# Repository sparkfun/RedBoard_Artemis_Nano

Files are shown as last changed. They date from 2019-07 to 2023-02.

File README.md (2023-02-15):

SparkFun RedBoard Artemis Nano
============================

SparkFun RedBoard Artemis Nano

[*SparkFun RedBoard Artemis Nano (DEV-15443)*](https://www.sparkfun.com/products/15443)

We like to joke the Artemis Nano is a party on the front and business on the back. And that's by design! All the important LEDs, connectors, labels, and buttons are presented on the front for the best user experience with all the supporting circuitry on the rear of the board. The RedBoard Artemis Nano is a minimal but extremely handy implementation of the Artemis module. A light weight, 0.8mm thick PCB, with on board lipo-battery charging and a Qwiic connector, this board is easy to implement into very small projects. A dual row of ground connections make it easy to add lots of buttons, LEDs, and anything that requires its own GND connection. At the same time, the board is breadboard compatible! 

A modern USB-C connector makes programming easy. The Nano is fully compatible with the SparkFun's Arduino core and can be programmed easily under the Arduino IDE. We've also exposed the JTAG connector for more advanced users who prefer to use the power and speed of professional tools. If you're looking for a simple, cost-effective board to replace your aging Arduino Uno or Arduino Nano, look no further. We've even added a digital MEMS microphone for folks wanting to experiment with always-on voice commands with TensorFlow and machine learning.
 
With 1M flash and 384k RAM you'll have plenty of room for your sketches. The Artemis module runs at 48MHz with a 96MHz turbo mode available and with Bluetooth to boot!

The SparkFun Artemis Nano is an incredibly flexible device for a small footprint but if you're looking for all the bells and whistles, be sure to checkout our RedBoard and ATP footprints for even more I/O and capabilities.

Repository Contents
-------------------
* **/Hardware** - Eagle design files (.brd, .sch)

Documentation
-------------------
* **[Hookup Guide for the RedBoard Artemis Nano](https://learn.sparkfun.com/tutorials/hookup-guide-for-the-sparkfun-redboard-artemis-nano)**
* **[Fritzing Part](https://github.com/sparkfun/Fritzing_Parts/blob/main/products/15443_sfe_redboard_artemis_nano.fzpz)** - Fritzing diagrams for SparkFun products.
* **[Artemis Development with Arduino](https://learn.sparkfun.com/tutorials/artemis-development-with-arduino)**
* **[Ambiq Apollo3 SDK SetUp](https://learn.sparkfun.com/tutorials/using-sparkfun-edge-board-with-ambiq-apollo3-sdk)**
* **[Designing with the SparkFun Artemis](https://learn.sparkfun.com/tutorials/designing-with-the-sparkfun-artemis)**
* **[CH340E USB to serial IC Drivers](https://www.sparkfun.com/ch340)**

License Information
-------------------

This product is _**open source**_! 

Please review the LICENSE.md file for license information. 

If you have any questions or concerns on licensing, please contact techsupport@sparkfun.com.

Please use, reuse, and modify these files as you see fit. Please maintain attribution to SparkFun Electronics and release any derivative under the same license.

Distributed as-is; no warranty is given.

- Your friends at SparkFun.

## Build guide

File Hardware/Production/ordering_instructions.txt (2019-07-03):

panel size, 213x97mm
PCB thickness, 0.8mm
number of layers, 4
soldermask color, Red
silkscreen color, White
oz copper, 1oz
finish, HASL lead free
stencils, top+bottom
pcs per panel, 16
min trace width, 0.152400mm / 0.006000in
min drill size, 0.304800mm / 0.012000in
filename to layer stackup 1/2/3/4: GTL, GL2, GL3, GBL

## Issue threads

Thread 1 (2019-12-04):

Expose ITM/SWO pin on SWD/JTAG Connector

oclyke, 2019-12-04:
Will you consider adding a free ITM/SWO pin to the SWD/JTAG connector as is demonstrated on the [Edge](https://cdn.sparkfun.com/assets/2/b/7/4/d/SparkFun_Edge_Schematic.pdf) board? This affords users a different ('pro') way to do debug printing and possibly frees up a UART for another purpose. Inspired by https://github.com/sparkfun/SparkFun_Apollo3_AmbiqSuite_BSPs/issues/19

oclyke, 2019-12-13:
OOPS. I totally overlooked the SWO pin here and made all this fuss over nothing. Sorry!

Closed 2019-12-13.

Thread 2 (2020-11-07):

Which USB C Connector is used ?

Thore-Krug, 2020-11-07:
I wanted to know which USB C Connector was used on the Board and opened the Design Files but there is no info on the Specific USB Connector used.   I also noted that the libary used for the connector was not included in the Design Files.

Signed off by: Thore Krug opensource[at]thorekrug.de

nseidle, 2020-11-09:
[This one](https://www.sparkfun.com/products/15111) from BSC.

Thore-Krug, 2020-11-09:
Thank you

Closed 2020-11-09.

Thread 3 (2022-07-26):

Hardware Feature request/suggestions

edringel, 2022-07-26:
Forgive me if I've done this incorrectly, but here goes--
I'd like to suggest an Artemis based board designed to maximize low power features. I'm using the Artemis Nano in a remote sensor that is turned on and off by a low power timer. Once I am done with development, I will be cutting traces, and removing SMD resistors and LEDs to minimize current draw. I think one of the draws of the Artemis is its super low power potential, and a board designed to maximize that facet of use might rouse some interest. The design changes are simple (I think) and would be great for a project sitting off in the woods running on battery for months at a time--

Rather than a design paradigm assuming that the device is mostly on and occasionally needs to be turned off, consider a design that assumes that the device is mostly off and is turned on periodically to do something and then gets turned off. Would pair nicely with Adafruit TPL5111 (NOT the TPL5110, which is slightly different.) Or you guys could cobble together your own ;)
1) Do not use a pullup resistor for the regulator's enable pin. Every time the enable pin is brought low by tying it to ground, there is current through the 10K resistor which over time adds up. Use either a high resistance pulldown resistor or leave it to the user.
2) All LEDs have a trace that can be cut so that they no longer are active. Once design work is done, cutting the traces would reduce current by milliamps.
3) No microphone.
4) Hobbyist level library to shut off unneeded peripherals. Something nice and Arduino IDE friendly
Thanks for considering this.
Ed

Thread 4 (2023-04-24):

Using with a LiPo cell + solar panel

jerabaul29, 2023-04-24:
Is it enough to simply:

- connect a LiPo cell on the battery connector,
- connect a 6V solar panel between the Vin and GND

to use the RedBoard Nano with LiPo + Solar panel? If so, maybe having a dedicated section / explanation in addition to what is already present in the product page would be good, just to discuss this combination; if I did not miss anything, there is no detailed documentation on this available yet :) . If not, any other way to get a combination RedBoard Artemis Nano + LiPo + solar panel working with as little work as possible? :)

(what we were discussing about @gauteh :) ).

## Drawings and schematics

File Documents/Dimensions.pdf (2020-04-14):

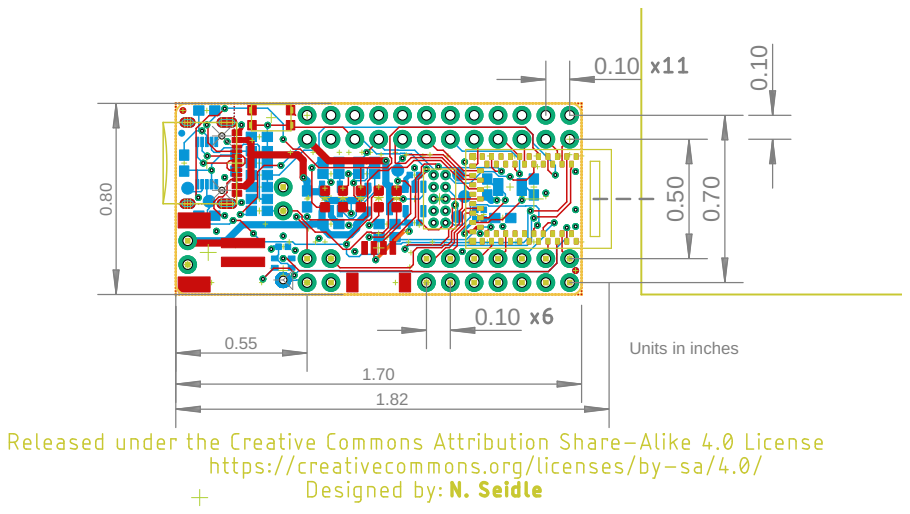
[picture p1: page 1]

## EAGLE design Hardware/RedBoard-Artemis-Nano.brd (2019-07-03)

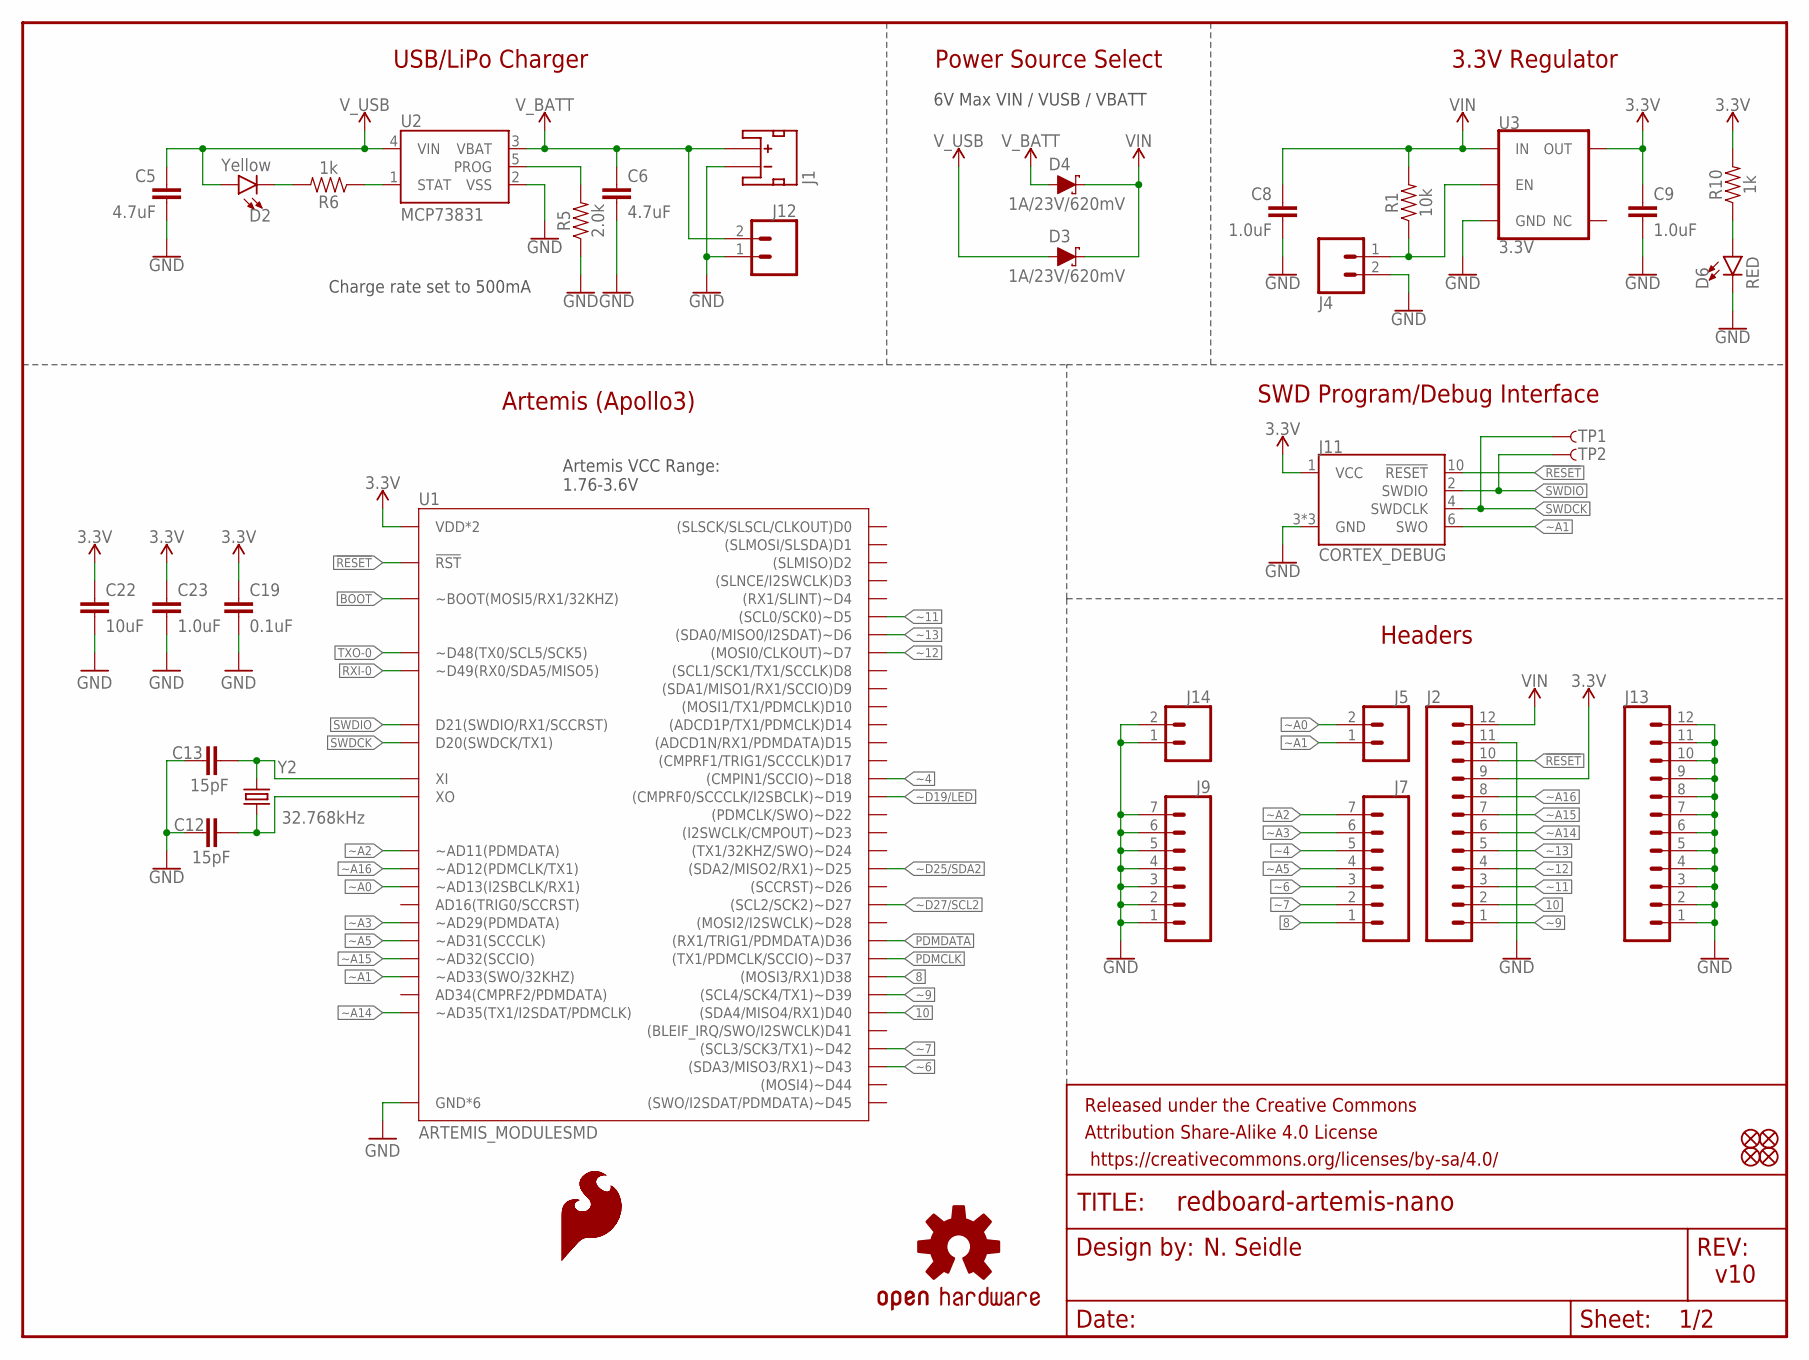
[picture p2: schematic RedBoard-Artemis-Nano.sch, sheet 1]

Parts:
C5, C6: 4.7uF; 0603
C8, C9, C23: 1.0uF; 0402-TIGHT
C12, C13: 15pF; 0603
C19: 0.1uF; 0402-TIGHT
C22: 10uF; 0603
D2: Yellow; LED-0603
D3, D4: 1A/23V/620mV; SOD-323
D6: RED; LED-0603
FD1, FD2, FD3, FD4: FIDUCIALUFIDUCIAL; FIDUCIAL-MICRO
FRAME1: FRAME-LETTER; CREATIVE_COMMONS
J1: JST_2MM_MALE; JST-2-SMD
J2, J13: CONN_12NO_SILK; 1X12_NO_SILK
J4, J5, J12, J14: CONN_021X02_NO_SILK; 1X02_NO_SILK
J7, J9: CONN_07NO_SILK; 1X07_NO_SILK
J11: CORTEX_DEBUG; 2X5-PTH-1.27MM-NO_SILK
LOGO1, LOGO4: SFE_LOGO_FLAME.1_INCH; SFE_LOGO_FLAME_.1
LOGO2: OSHW-LOGONO_SILK; DUMMY
R1: 10k; 0603
R5: 2.0k; 0603
R6, R10: 1k; 0603
TP1, TP2: TEST-POINT3X5; PAD.03X.05
U1: ARTEMIS_MODULESMD; ARTEMIS_FP
U2: MCP73831; SOT23-5
U3: 3.3V; SOT23-5
Y2: 32.768kHz; CRYSTAL-SMD-3.2X1.5MM

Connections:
3.3V: C9.1, C19.2, C22.1, C23.1, J2.9, J11.1 (VCC), R10.2, U1.VDD@36 (VDD*2), U1.VDD@37 (VDD*2), U3.5 (OUT); also elsewhere on the board
8: J7.1, U1.D38 ((MOSI3/RX1)D38)
10: J2.2, U1.D40 ((SDA4/MISO4/RX1)D40)
!RESET: J2.10, J11.10 (!RESET), U1.~RST (!RST); also elsewhere on the board
BOOT: U1.BOOT (~BOOT(MOSI5/RX1/32KHZ)); also elsewhere on the board
GND: C5.2, C6.2, C8.2, C9.2, C12.1, C13.1, C19.1, C22.2, C23.2, D6.C, J1.1 (-), J2.11, J4.2, J9.1, J9.2, J9.3, J9.4, J9.5, J9.6, J9.7, J11.3 (GND), J11.5 (GND), J11.9 (GND), J12.1, J13.1, J13.2, J13.3, J13.4, J13.5, J13.6, J13.7, J13.8, J13.9, J13.10, J13.11, J13.12, J14.1, J14.2, R5.1, U1.GND@1 (GND*6), U1.GND@22 (GND*6), U1.GND@38 (GND*6), U1.GND@39 (GND*6), U1.GND@47 (GND*6), U1.GND@59 (GND*6), U2.2 (VSS), U3.2 (GND); also elsewhere on the board
unnamed: R5.2, U2.5 (PROG)
unnamed: C12.2, U1.XO, Y2.P$2 (2)
unnamed: D2.C, R6.2
unnamed: R6.1, U2.1 (STAT)
unnamed: C13.2, U1.XI, Y2.P$1 (1)
unnamed: D6.A, R10.1
PDMCLK: U1.~D37 ((TX1/PDMCLK/SCCIO)~D37); also elsewhere on the board
PDMDATA: U1.D36 ((RX1/TRIG1/PDMDATA)D36); also elsewhere on the board
RXI-0: U1.RXI-0 (~D49(RX0/SDA5/MISO5)); also elsewhere on the board
SWDCK: J11.4 (SWDCLK), TP1.P$1, U1.SWDCK (D20(SWDCK/TX1))
SWDIO: J11.2 (SWDIO), TP2.P$1, U1.SWDIO (D21(SWDIO/RX1/SCCRST))
TXO-0: U1.TXO-0 (~D48(TX0/SCL5/SCK5)); also elsewhere on the board
VIN: C8.1, D3.C, D4.C, J2.12, R1.2, U3.1 (IN)
VREG_EN: J4.1, R1.1, U3.3 (EN)
V_BATT: C6.1, D4.A, J1.2 (+), J12.2, U2.3 (VBAT)
V_USB: C5.1, D2.A, D3.A, U2.4 (VIN); also elsewhere on the board
~4: J7.5, U1.~D18 ((CMPIN1/SCCIO)~D18)
~6: J7.3, U1.~D43 ((SDA3/MISO3/RX1)~D43)
~7: J7.2, U1.~D42 ((SCL3/SCK3/TX1)~D42)
~9: J2.1, U1.~D39 ((SCL4/SCK4/TX1)~D39)
~11: J2.3, U1.~D5 ((SCL0/SCK0)~D5)
~12: J2.4, U1.D7 ((MOSI0/CLKOUT)~D7)
~13: J2.5, U1.~D6 ((SDA0/MISO0/I2SDAT)~D6)
~A0: J5.2, U1.~AD13 (~AD13(I2SBCLK/RX1))
~A1: J5.1, J11.6 (SWO), U1.~AD33/SWO (~AD33(SWO/32KHZ))
~A2: J7.7, U1.~AD11 (~AD11(PDMDATA))
~A3: J7.6, U1.~AD29 (~AD29(PDMDATA))
~A5: J7.4, U1.~AD31 (~AD31(SCCCLK))
~A14: J2.6, U1.~AD35 (~AD35(TX1/I2SDAT/PDMCLK))
~A15: J2.7, U1.~AD32 (~AD32(SCCIO))
~A16: J2.8, U1.~AD12 (~AD12(PDMCLK/TX1))
~D19/LED: U1.~D19 ((CMPRF0/SCCCLK/I2SBCLK)~D19); also elsewhere on the board
~D25/SDA2: U1.~D25 ((SDA2/MISO2/RX1)~D25); also elsewhere on the board
~D27/SCL2: U1.~D27 ((SCL2/SCK2)~D27); also elsewhere on the board

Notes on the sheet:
v10
N. Seidle
SWD Program/Debug Interface
Headers
Artemis (Apollo3)
USB/LiPo Charger
Power Source Select
3.3V Regulator
Artemis VCC Range: 1.76-3.6V
Charge rate set to 500mA
6V Max VIN / VUSB / VBATT

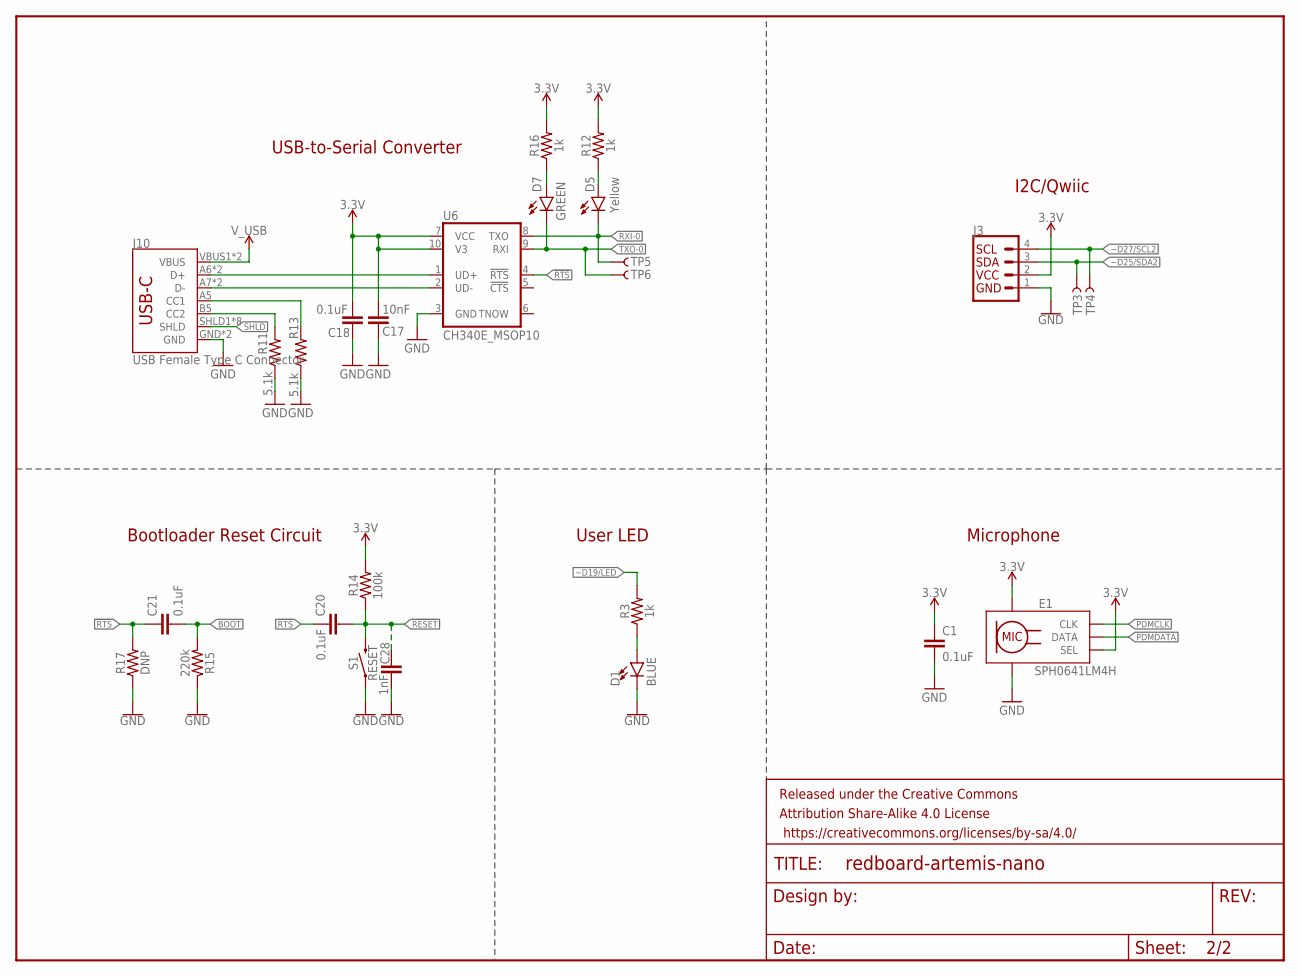
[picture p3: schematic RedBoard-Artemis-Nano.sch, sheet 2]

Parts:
C1: 0.1uF; 0402-TIGHT
C17: 10nF; 0603
C18, C20, C21: 0.1uF; 0603
C28: 1nF; 0603
D1: BLUE; LED-0603
D5: Yellow; LED-0603
D7: GREEN; LED-0603
E1: SPH0641LM4H; SPH0641LM4H-1_MICROPHONE
FRAME2: FRAME-LETTERNO_PACKAGE; DUMMY
J3: QWIIC_CONNECTORJS-1MM; JST04_1MM_RA
J10: USB Female Type C Connector; USB-C-16P-4LAYER-ISOLATED
R3, R12, R16: 1k; 0603
R11, R13: 5.1k; 0603
R14: 100k; 0603
R15: 220k; 0603
R17: DNP; 0603
S1: RESET; TACTILE_SWITCH_SMD_4.6X2.8MM
TP3, TP4, TP5, TP6: TEST-POINT3X5; PAD.03X.05
U6: CH340E_MSOP10; MSOP10

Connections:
3.3V: C1.1, C17.1, C18.1, E1.2 (SEL), E1.5 (VDD), J3.2, R12.2, R14.2, R16.2, U6.7 (VCC), U6.10 (V3); also elsewhere on the board
!RESET: C20.2, C28.1, R14.1, S1.3 (2), S1.4 (2); also elsewhere on the board
!RTS: C20.1, C21.1, R17.2, U6.4 (!RTS)
BOOT: C21.2, R15.2; also elsewhere on the board
CC1: J10.A5 (CC1), R13.2
CC2: J10.B5 (CC2), R11.2
D+1: J10.A6 (D+), J10.B6 (D+), U6.1 (UD+)
D-1: J10.A7 (D-), J10.B7 (D-), U6.2 (UD-)
GND: C1.2, C17.2, C18.2, C28.2, D1.C, E1.3 (GND), E1.6 (GND), E1.7 (GND), E1.8 (GND), J3.1, J10.GND, J10.GND2 (GND), R11.1, R13.1, R15.1, R17.1, S1.1, S1.2 (1), U6.3 (GND); also elsewhere on the board
unnamed: D7.A, R16.1
unnamed: D1.A, R3.1
unnamed: D5.A, R12.1
PDMCLK: E1.4 (CLK); also elsewhere on the board
PDMDATA: E1.1 (DATA); also elsewhere on the board
RXI-0: D5.C, TP5.P$1, U6.8 (TXO); also elsewhere on the board
SHLD: J10.SHLD1 (SHLD), J10.SHLD2 (SHLD), J10.SHLD3 (SHLD), J10.SHLD4 (SHLD), J10.SHLD5 (SHLD), J10.SHLD6 (SHLD), J10.SHLD7 (SHLD), J10.SHLD8 (SHLD)
TXO-0: D7.C, TP6.P$1, U6.9 (RXI); also elsewhere on the board
V_USB: J10.VBUS1 (VBUS), J10.VBUS2 (VBUS); also elsewhere on the board
~D19/LED: R3.2; also elsewhere on the board
~D25/SDA2: J3.3, TP3.P$1; also elsewhere on the board
~D27/SCL2: J3.4, TP4.P$1; also elsewhere on the board

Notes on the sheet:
Microphone
USB-to-Serial Converter
Bootloader Reset Circuit
User LED
I2C/Qwiic

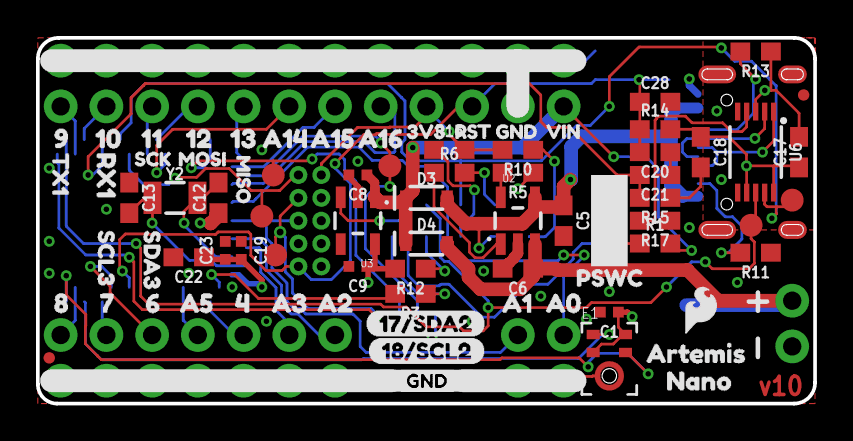
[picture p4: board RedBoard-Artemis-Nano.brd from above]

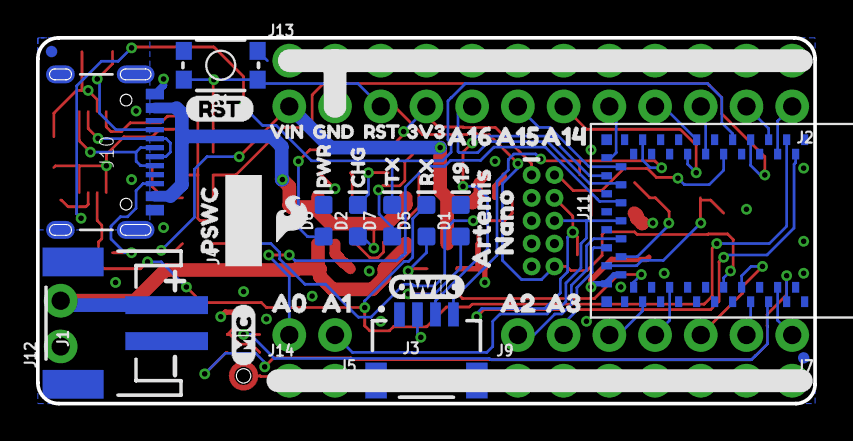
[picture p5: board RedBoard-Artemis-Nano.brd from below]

Board: 4 copper layers, 43.2 x 20.3 mm, 126 parts (46 on the bottom side), 49 nets.

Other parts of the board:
U$1, U$49: 3V316
U$2: ____GND____2
U$3, U$38: RST19
U$4, U$23: PSWC4
U$5: CHG26
U$6: PWR27
U$7, U$33: GND17
U$8: QWIIC#LOGO#JPG
U$9, U$20: A00
U$10: A57
U$11: SCL30
U$12, U$54: A145
U$13, U$22: ARTEMIS6
U$14: MISO5
U$15: MIC0
U$16: MOSI4
U$17, U$24: NANO7
U$18: SCK3
U$19, U$42: A32
U$21, U$41: A21
U$25: PRODUCTION_INSTRUCTIONS
U$26: 191
U$27, U$39: VIN19
U$28, U$55: A156
U$30: GND2
U$31: SDA31
U$32: 46
U$34, U$40: A10
U$35: 68
U$36: 79
U$37: 810
U$45: 90
U$46: 101
U$47: 112
U$48, U$56: A167
U$50: RX10
U$51: RST1
U$52: 123
U$53: 134
U$57: 17#SDA21
U$59: TX12
U$60: 18#SCL20
U$85: RX23
U$86: TX22

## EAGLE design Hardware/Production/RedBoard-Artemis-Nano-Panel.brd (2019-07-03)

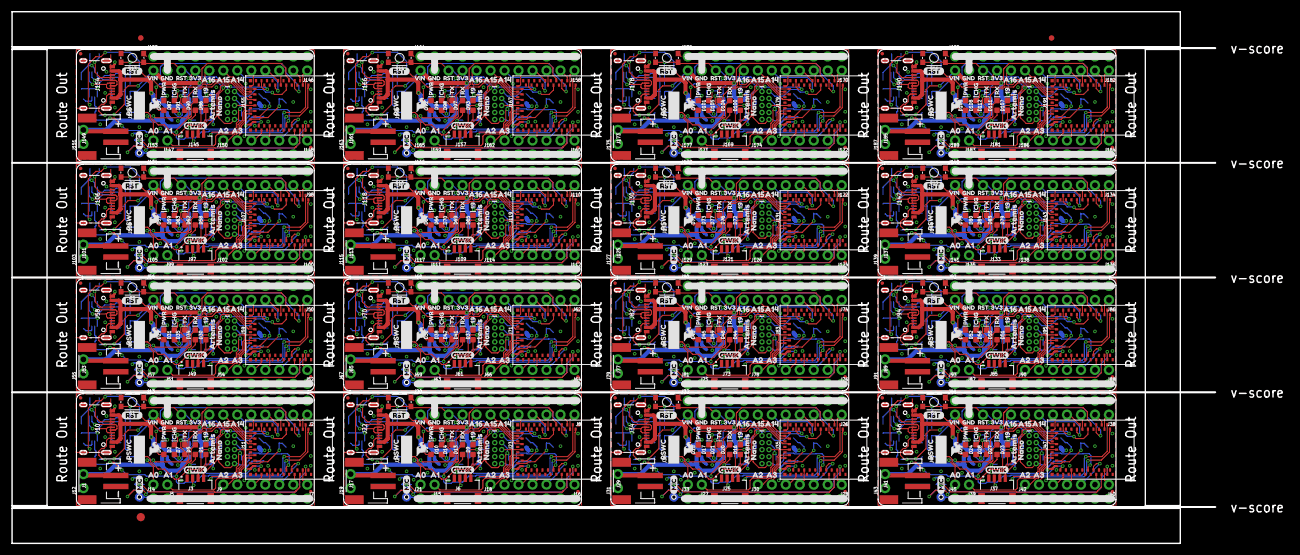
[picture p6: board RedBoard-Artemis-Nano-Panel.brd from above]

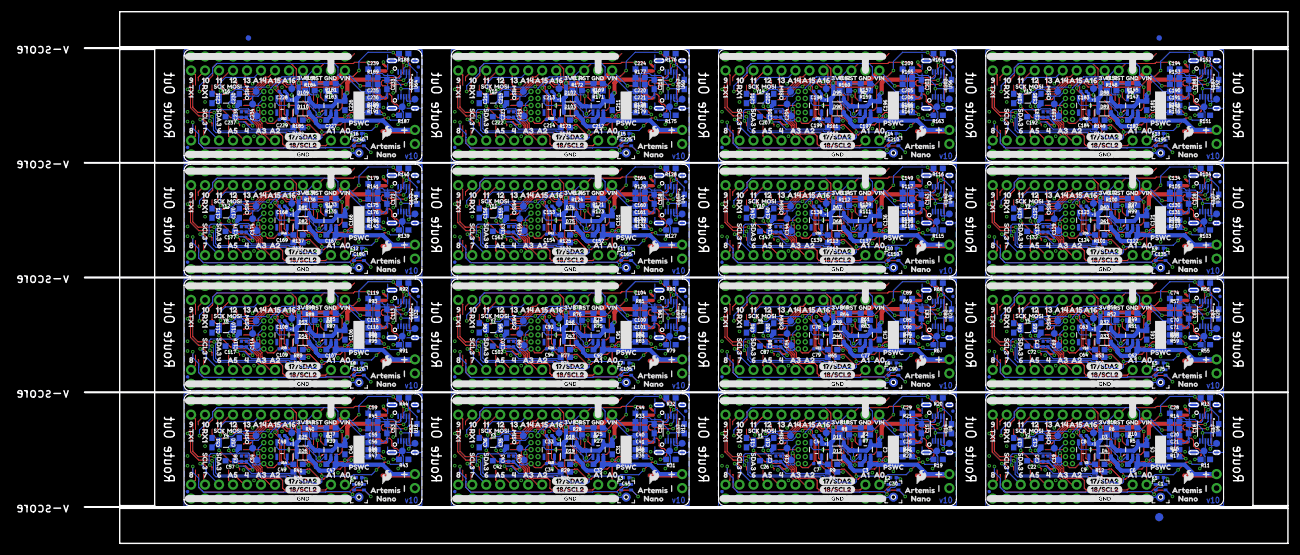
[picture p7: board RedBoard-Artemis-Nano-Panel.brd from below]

Board: 4 copper layers, 218.4 x 96.5 mm, 1990 parts (1267 on the bottom side), 784 nets.

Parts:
C1, C16, C19, C30, C39, C45, C54, C60, C69, C75, C84, C90, C99, C105, C114, C120, C129, C135, C144, C150, C159, C165, C174, C180, C189, C195, C204, C210, C219, C225, C234, C240: 0.1uF; 0402-TIGHT
C2, C3, C5, C6, C31, C32, C46, C47, C61, C62, C76, C77, C91, C92, C106, C107, C121, C122, C136, C137, C151, C152, C166, C167, C181, C182, C196, C197, C211, C212, C226, C227: 4.7uF; 0603
C4, C7, C8, C9, C23, C27, C33, C34, C43, C48, C49, C58, C63, C64, C73, C78, C79, C88, C93, C94, C103, C108, C109, C118, C123, C124, C133, C138, C139, C148, C153, C154, C163, C168, C169, C178, C183, C184, C193, C198, C199, C208, C213, C214, C223, C228, C229, C238: 1.0uF; 0402-TIGHT
C10, C11, C12, C13, C35, C36, C50, C51, C65, C66, C80, C81, C95, C96, C110, C111, C125, C126, C140, C141, C155, C156, C170, C171, C185, C186, C200, C201, C215, C216, C230, C231: 15pF; 0603
C14, C17, C37, C52, C67, C82, C97, C112, C127, C142, C157, C172, C187, C202, C217, C232: 10nF; 0603
C15, C18, C20, C21, C24, C25, C38, C40, C41, C53, C55, C56, C68, C70, C71, C83, C85, C86, C98, C100, C101, C113, C115, C116, C128, C130, C131, C143, C145, C146, C158, C160, C161, C173, C175, C176, C188, C190, C191, C203, C205, C206, C218, C220, C221, C233, C235, C236: 0.1uF; 0603
C22, C26, C42, C57, C72, C87, C102, C117, C132, C147, C162, C177, C192, C207, C222, C237: 10uF; 0603
C28, C29, C44, C59, C74, C89, C104, C119, C134, C149, C164, C179, C194, C209, C224, C239: 1nF; 0603
D1, D9, D16, D23, D30, D37, D44, D51, D58, D65, D72, D79, D86, D93, D100, D107: BLUE; LED-0603
D2, D5, D10, D13, D17, D20, D24, D27, D31, D34, D38, D41, D45, D48, D52, D55, D59, D62, D66, D69, D73, D76, D80, D83, D87, D90, D94, D97, D101, D104, D108, D111: Yellow; LED-0603
D3, D4, D11, D12, D18, D19, D25, D26, D32, D33, D39, D40, D46, D47, D53, D54, D60, D61, D67, D68, D74, D75, D81, D82, D88, D89, D95, D96, D102, D103, D109, D110: 1A/23V/620mV; SOD-323
D6, D8, D15, D22, D29, D36, D43, D50, D57, D64, D71, D78, D85, D92, D99, D106: RED; LED-0603
D7, D14, D21, D28, D35, D42, D49, D56, D63, D70, D77, D84, D91, D98, D105, D112: GREEN; LED-0603
E1, E2, E3, E4, E5, E6, E7, E8, E9, E10, E11, E12, E13, E14, E15, E16: SPH0641LM4H; SPH0641LM4H-1_MICROPHONE
E$1, E$2, E$3, E$4: FIDUCIAL-1X2
E$5, E$6: FIDUCIAL-1.5X3
FD1, FD2, FD3, FD4, FD5, FD6, FD7, FD8, FD9, FD10, FD11, FD12, FD13, FD14, FD15, FD16, FD17, FD18, FD19, FD20, FD21, FD22, FD23, FD24, FD25, FD26, FD27, FD28, FD29, FD30, FD31, FD32, FD33, FD34, FD35, FD36, FD37, FD38, FD39, FD40, FD41, FD42, FD43, FD44, FD45, FD46, FD47, FD48, FD49, FD50, FD51, FD52, FD53, FD54, FD55, FD56, FD57, FD58, FD59, FD60, FD61, FD62, FD63, FD64: FIDUCIALUFIDUCIAL; FIDUCIAL-MICRO
FRAME1, FRAME2, FRAME3, FRAME4, FRAME5, FRAME6, FRAME7, FRAME8, FRAME9, FRAME10, FRAME11, FRAME12, FRAME13, FRAME14, FRAME15, FRAME16: FRAME-LETTERNO_PACKAGE; DUMMY
J1, J17, J29, J41, J53, J65, J77, J89, J101, J113, J125, J137, J149, J161, J173, J185: JST-2-SMD
J2, J8, J13, J20, J26, J32, J38, J44, J50, J56, J62, J68, J74, J80, J86, J92, J98, J104, J110, J116, J122, J128, J134, J140, J146, J152, J158, J164, J170, J176, J182, J188: 1X12_NO_SILK
J3, J6, J25, J37, J49, J61, J73, J85, J97, J109, J121, J133, J145, J157, J169, J181: JST04_1MM_RA
J4, J5, J12, J14, J15, J19, J21, J24, J27, J31, J33, J36, J39, J43, J45, J48, J51, J55, J57, J60, J63, J67, J69, J72, J75, J79, J81, J84, J87, J91, J93, J96, J99, J103, J105, J108, J111, J115, J117, J120, J123, J127, J129, J132, J135, J139, J141, J144, J147, J151, J153, J156, J159, J163, J165, J168, J171, J175, J177, J180, J183, J187, J189, J192: 1X02_NO_SILK
J7, J9, J16, J18, J28, J30, J40, J42, J52, J54, J64, J66, J76, J78, J88, J90, J100, J102, J112, J114, J124, J126, J136, J138, J148, J150, J160, J162, J172, J174, J184, J186: 1X07_NO_SILK
J10, J22, J34, J46, J58, J70, J82, J94, J106, J118, J130, J142, J154, J166, J178, J190: USB Female Type C Connector; USB-C-16P-4LAYER-ISOLATED
J11, J23, J35, J47, J59, J71, J83, J95, J107, J119, J131, J143, J155, J167, J179, J191: CORTEX_DEBUG; 2X5-PTH-1.27MM-NO_SILK
LOGO1, LOGO2, LOGO3, LOGO4, LOGO5, LOGO6, LOGO7, LOGO8, LOGO9, LOGO10, LOGO11, LOGO12, LOGO13, LOGO14, LOGO15, LOGO16, LOGO17, LOGO18, LOGO19, LOGO20, LOGO21, LOGO22, LOGO23, LOGO24, LOGO25, LOGO26, LOGO27, LOGO28, LOGO29, LOGO30, LOGO31, LOGO32: SFE_LOGO_FLAME.1_INCH; SFE_LOGO_FLAME_.1
R1, R24, R36, R48, R60, R72, R84, R96, R108, R120, R132, R144, R156, R168, R180, R192: 10k; 0603
R2, R3, R4, R6, R8, R9, R10, R12, R16, R18, R25, R26, R28, R29, R30, R37, R38, R40, R41, R42, R49, R50, R52, R53, R54, R61, R62, R64, R65, R66, R73, R74, R76, R77, R78, R85, R86, R88, R89, R90, R97, R98, R100, R101, R102, R109, R110, R112, R113, R114, R121, R122, R124, R125, R126, R133, R134, R136, R137, R138, R145, R146, R148, R149, R150, R157, R158, R160, R161, R162, R169, R170, R172, R173, R174, R181, R182, R184, R185, R186: 1k; 0603
R5, R7, R27, R39, R51, R63, R75, R87, R99, R111, R123, R135, R147, R159, R171, R183: 2.0k; 0603
R11, R13, R19, R20, R31, R32, R43, R44, R55, R56, R67, R68, R79, R80, R91, R92, R103, R104, R115, R116, R127, R128, R139, R140, R151, R152, R163, R164, R175, R176, R187, R188: 5.1k; 0603
R14, R21, R33, R45, R57, R69, R81, R93, R105, R117, R129, R141, R153, R165, R177, R189: 100k; 0603
R15, R22, R34, R46, R58, R70, R82, R94, R106, R118, R130, R142, R154, R166, R178, R190: 220k; 0603
R17, R23, R35, R47, R59, R71, R83, R95, R107, R119, R131, R143, R155, R167, R179, R191: DNP; 0603
S1, S2, S3, S4, S5, S6, S7, S8, S9, S10, S11, S12, S13, S14, S15, S16: RESET; TACTILE_SWITCH_SMD_4.6X2.8MM
TP1, TP2, TP9, TP10, TP15, TP16, TP21, TP22, TP27, TP28, TP33, TP34, TP39, TP40, TP45, TP46, TP51, TP52, TP57, TP58, TP63, TP64, TP69, TP70, TP75, TP76, TP81, TP82, TP87, TP88, TP93, TP94: PAD.03X.05
TP3, TP4, TP5, TP6, TP7, TP8, TP11, TP12, TP13, TP14, TP17, TP18, TP19, TP20, TP23, TP24, TP25, TP26, TP29, TP30, TP31, TP32, TP35, TP36, TP37, TP38, TP41, TP42, TP43, TP44, TP47, TP48, TP49, TP50, TP53, TP54, TP55, TP56, TP59, TP60, TP61, TP62, TP65, TP66, TP67, TP68, TP71, TP72, TP73, TP74, TP77, TP78, TP79, TP80, TP83, TP84, TP85, TP86, TP89, TP90, TP91, TP92, TP95, TP96: TEST-POINT3X5; PAD.03X.05
U1, U7, U11, U15, U19, U23, U27, U31, U35, U39, U43, U47, U51, U55, U59, U63: ARTEMIS_MODULESMD; ARTEMIS_FP
U2, U4, U9, U13, U17, U21, U25, U29, U33, U37, U41, U45, U49, U53, U57, U61: MCP73831; SOT23-5
U3, U5, U10, U14, U18, U22, U26, U30, U34, U38, U42, U46, U50, U54, U58, U62: 3.3V; SOT23-5
U6, U8, U12, U16, U20, U24, U28, U32, U36, U40, U44, U48, U52, U56, U60, U64: CH340E_MSOP10; MSOP10
U$1, U$49, U$63, U$70, U$123, U$130, U$181, U$188, U$239, U$246, U$297, U$304, U$355, U$362, U$413, U$420, U$471, U$478, U$529, U$536, U$587, U$594, U$645, U$652, U$703, U$710, U$761, U$768, U$819, U$826, U$877, U$884: 3V316
U$2, U$80, U$140, U$198, U$256, U$314, U$372, U$430, U$488, U$546, U$604, U$662, U$720, U$778, U$836, U$894: ____GND____2
U$3, U$38, U$62, U$68, U$122, U$128, U$180, U$186, U$238, U$244, U$296, U$302, U$354, U$360, U$412, U$418, U$470, U$476, U$528, U$534, U$586, U$592, U$644, U$650, U$702, U$708, U$760, U$766, U$818, U$824, U$876, U$882: RST19
U$4, U$23, U$115, U$116, U$173, U$174, U$231, U$232, U$289, U$290, U$347, U$348, U$405, U$406, U$463, U$464, U$521, U$522, U$579, U$580, U$637, U$638, U$695, U$696, U$753, U$754, U$811, U$812, U$869, U$870, U$927, U$928: PSWC4
U$5, U$29, U$117, U$175, U$233, U$291, U$349, U$407, U$465, U$523, U$581, U$639, U$697, U$755, U$813, U$871: CHG26
U$6, U$43, U$118, U$176, U$234, U$292, U$350, U$408, U$466, U$524, U$582, U$640, U$698, U$756, U$814, U$872: PWR27
U$7, U$33, U$58, U$67, U$120, U$127, U$178, U$185, U$236, U$243, U$294, U$301, U$352, U$359, U$410, U$417, U$468, U$475, U$526, U$533, U$584, U$591, U$642, U$649, U$700, U$707, U$758, U$765, U$816, U$823, U$874, U$881: GND17
U$8, U$44, U$119, U$177, U$235, U$293, U$351, U$409, U$467, U$525, U$583, U$641, U$699, U$757, U$815, U$873: QWIIC#LOGO#JPG
U$9, U$20, U$82, U$106, U$142, U$164, U$200, U$222, U$258, U$280, U$316, U$338, U$374, U$396, U$432, U$454, U$490, U$512, U$548, U$570, U$606, U$628, U$664, U$686, U$722, U$744, U$780, U$802, U$838, U$860, U$896, U$918: A00
U$10, U$103, U$161, U$219, U$277, U$335, U$393, U$451, U$509, U$567, U$625, U$683, U$741, U$799, U$857, U$915: A57
U$11, U$100, U$158, U$216, U$274, U$332, U$390, U$448, U$506, U$564, U$622, U$680, U$738, U$796, U$854, U$912: SCL30
U$12, U$54, U$97, U$108, U$155, U$166, U$213, U$224, U$271, U$282, U$329, U$340, U$387, U$398, U$445, U$456, U$503, U$514, U$561, U$572, U$619, U$630, U$677, U$688, U$735, U$746, U$793, U$804, U$851, U$862, U$909, U$920: A145
U$13, U$22, U$71, U$77, U$131, U$137, U$189, U$195, U$247, U$253, U$305, U$311, U$363, U$369, U$421, U$427, U$479, U$485, U$537, U$543, U$595, U$601, U$653, U$659, U$711, U$717, U$769, U$775, U$827, U$833, U$885, U$891: ARTEMIS6
U$14, U$73, U$133, U$191, U$249, U$307, U$365, U$423, U$481, U$539, U$597, U$655, U$713, U$771, U$829, U$887: MISO5
U$15, U$72, U$132, U$190, U$248, U$306, U$364, U$422, U$480, U$538, U$596, U$654, U$712, U$770, U$828, U$886: MIC0
U$16, U$74, U$134, U$192, U$250, U$308, U$366, U$424, U$482, U$540, U$598, U$656, U$714, U$772, U$830, U$888: MOSI4
U$17, U$24, U$75, U$78, U$135, U$138, U$193, U$196, U$251, U$254, U$309, U$312, U$367, U$370, U$425, U$428, U$483, U$486, U$541, U$544, U$599, U$602, U$657, U$660, U$715, U$718, U$773, U$776, U$831, U$834, U$889, U$892: NANO7
U$18, U$76, U$136, U$194, U$252, U$310, U$368, U$426, U$484, U$542, U$600, U$658, U$716, U$774, U$832, U$890: SCK3
U$19, U$42, U$91, U$104, U$149, U$162, U$207, U$220, U$265, U$278, U$323, U$336, U$381, U$394, U$439, U$452, U$497, U$510, U$555, U$568, U$613, U$626, U$671, U$684, U$729, U$742, U$787, U$800, U$845, U$858, U$903, U$916: A32
U$21, U$41, U$90, U$105, U$148, U$163, U$206, U$221, U$264, U$279, U$322, U$337, U$380, U$395, U$438, U$453, U$496, U$511, U$554, U$569, U$612, U$627, U$670, U$685, U$728, U$743, U$786, U$801, U$844, U$859, U$902, U$917: A21
U$25, U$81, U$141, U$199, U$257, U$315, U$373, U$431, U$489, U$547, U$605, U$663, U$721, U$779, U$837, U$895: PRODUCTION_INSTRUCTIONS
U$26, U$114, U$172, U$230, U$288, U$346, U$404, U$462, U$520, U$578, U$636, U$694, U$752, U$810, U$868, U$926: 191
U$27, U$39, U$61, U$69, U$121, U$129, U$179, U$187, U$237, U$245, U$295, U$303, U$353, U$361, U$411, U$419, U$469, U$477, U$527, U$535, U$585, U$593, U$643, U$651, U$701, U$709, U$759, U$767, U$817, U$825, U$875, U$883: VIN19
U$28, U$55, U$98, U$109, U$156, U$167, U$214, U$225, U$272, U$283, U$330, U$341, U$388, U$399, U$446, U$457, U$504, U$515, U$562, U$573, U$620, U$631, U$678, U$689, U$736, U$747, U$794, U$805, U$852, U$863, U$910, U$921: A156
U$30, U$79, U$139, U$197, U$255, U$313, U$371, U$429, U$487, U$545, U$603, U$661, U$719, U$777, U$835, U$893: GND2
U$31, U$101, U$159, U$217, U$275, U$333, U$391, U$449, U$507, U$565, U$623, U$681, U$739, U$797, U$855, U$913: SDA31
U$32, U$83, U$143, U$201, U$259, U$317, U$375, U$433, U$491, U$549, U$607, U$665, U$723, U$781, U$839, U$897: 46
U$34, U$40, U$89, U$107, U$147, U$165, U$205, U$223, U$263, U$281, U$321, U$339, U$379, U$397, U$437, U$455, U$495, U$513, U$553, U$571, U$611, U$629, U$669, U$687, U$727, U$745, U$785, U$803, U$843, U$861, U$901, U$919: A10
U$35, U$84, U$144, U$202, U$260, U$318, U$376, U$434, U$492, U$550, U$608, U$666, U$724, U$782, U$840, U$898: 68
U$36, U$87, U$145, U$203, U$261, U$319, U$377, U$435, U$493, U$551, U$609, U$667, U$725, U$783, U$841, U$899: 79
U$37, U$88, U$146, U$204, U$262, U$320, U$378, U$436, U$494, U$552, U$610, U$668, U$726, U$784, U$842, U$900: 810
U$45, U$92, U$150, U$208, U$266, U$324, U$382, U$440, U$498, U$556, U$614, U$672, U$730, U$788, U$846, U$904: 90
U$46, U$93, U$151, U$209, U$267, U$325, U$383, U$441, U$499, U$557, U$615, U$673, U$731, U$789, U$847, U$905: 101
U$47, U$94, U$152, U$210, U$268, U$326, U$384, U$442, U$500, U$558, U$616, U$674, U$732, U$790, U$848, U$906: 112
U$48, U$56, U$99, U$110, U$157, U$168, U$215, U$226, U$273, U$284, U$331, U$342, U$389, U$400, U$447, U$458, U$505, U$516, U$563, U$574, U$621, U$632, U$679, U$690, U$737, U$748, U$795, U$806, U$853, U$864, U$911, U$922: A167
U$50, U$111, U$169, U$227, U$285, U$343, U$401, U$459, U$517, U$575, U$633, U$691, U$749, U$807, U$865, U$923: RX10
U$51, U$64, U$124, U$182, U$240, U$298, U$356, U$414, U$472, U$530, U$588, U$646, U$704, U$762, U$820, U$878: RST1
U$52, U$95, U$153, U$211, U$269, U$327, U$385, U$443, U$501, U$559, U$617, U$675, U$733, U$791, U$849, U$907: 123
U$53, U$96, U$154, U$212, U$270, U$328, U$386, U$444, U$502, U$560, U$618, U$676, U$734, U$792, U$850, U$908: 134
U$57, U$112, U$170, U$228, U$286, U$344, U$402, U$460, U$518, U$576, U$634, U$692, U$750, U$808, U$866, U$924: 17#SDA21
U$59, U$102, U$160, U$218, U$276, U$334, U$392, U$450, U$508, U$566, U$624, U$682, U$740, U$798, U$856, U$914: TX12
U$60, U$113, U$171, U$229, U$287, U$345, U$403, U$461, U$519, U$577, U$635, U$693, U$751, U$809, U$867, U$925: 18#SCL20
U$65, U$85, U$125, U$183, U$241, U$299, U$357, U$415, U$473, U$531, U$589, U$647, U$705, U$763, U$821, U$879: RX23
U$66, U$86, U$126, U$184, U$242, U$300, U$358, U$416, U$474, U$532, U$590, U$648, U$706, U$764, U$822, U$880: TX22
Y1, Y2, Y3, Y4, Y5, Y6, Y7, Y8, Y9, Y10, Y11, Y12, Y13, Y14, Y15, Y16: 32.768kHz; CRYSTAL-SMD-3.2X1.5MM

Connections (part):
1: J16.1, U7.D38
2: J8.2, U7.D40
3: J28.1, U11.D38
3.3V: C1.1, C9.1, C17.1, C18.1, C19.2, C22.1, C23.1, E1.2, E1.5, J2.9, J3.2, J11.1, R10.2, R12.2, R14.2, R16.2, U1.VDD@36, U1.VDD@37, U3.5, U6.7, U6.10
3.3V1: C7.1, C14.1, C15.1, C16.2, C26.1, C27.1, C30.1, E2.2, E2.5, J6.2, J8.9, J23.1, R2.2, R9.2, R18.2, R21.2, U5.5, U7.VDD@36, U7.VDD@37, U8.7, U8.10
3.3V2: C34.1, C37.1, C38.1, C39.2, C42.1, C43.1, C45.1, E3.2, E3.5, J25.2, J26.9, J35.1, R25.2, R29.2, R30.2, R33.2, U10.5, U11.VDD@36, U11.VDD@37, U12.7, U12.10
3.3V3: C49.1, C52.1, C53.1, C54.2, C57.1, C58.1, C60.1, E4.2, E4.5, J37.2, J38.9, J47.1, R37.2, R41.2, R42.2, R45.2, U14.5, U15.VDD@36, U15.VDD@37, U16.7, U16.10
3.3V4: C64.1, C67.1, C68.1, C69.2, C72.1, C73.1, C75.1, E5.2, E5.5, J49.2, J50.9, J59.1, R49.2, R53.2, R54.2, R57.2, U18.5, U19.VDD@36, U19.VDD@37, U20.7, U20.10
3.3V5: C79.1, C82.1, C83.1, C84.2, C87.1, C88.1, C90.1, E6.2, E6.5, J61.2, J62.9, J71.1, R61.2, R65.2, R66.2, R69.2, U22.5, U23.VDD@36, U23.VDD@37, U24.7, U24.10
3.3V6: C94.1, C97.1, C98.1, C99.2, C102.1, C103.1, C105.1, E7.2, E7.5, J73.2, J74.9, J83.1, R73.2, R77.2, R78.2, R81.2, U26.5, U27.VDD@36, U27.VDD@37, U28.7, U28.10
3.3V7: C109.1, C112.1, C113.1, C114.2, C117.1, C118.1, C120.1, E8.2, E8.5, J85.2, J86.9, J95.1, R85.2, R89.2, R90.2, R93.2, U30.5, U31.VDD@36, U31.VDD@37, U32.7, U32.10
3.3V8: C124.1, C127.1, C128.1, C129.2, C132.1, C133.1, C135.1, E9.2, E9.5, J97.2, J98.9, J107.1, R97.2, R101.2, R102.2, R105.2, U34.5, U35.VDD@36, U35.VDD@37, U36.7, U36.10
3.3V9: C139.1, C142.1, C143.1, C144.2, C147.1, C148.1, C150.1, E10.2, E10.5, J109.2, J110.9, J119.1, R109.2, R113.2, R114.2, R117.2, U38.5, U39.VDD@36, U39.VDD@37, U40.7, U40.10
3.3V10: C154.1, C157.1, C158.1, C159.2, C162.1, C163.1, C165.1, E11.2, E11.5, J121.2, J122.9, J131.1, R121.2, R125.2, R126.2, R129.2, U42.5, U43.VDD@36, U43.VDD@37, U44.7, U44.10
3.3V11: C169.1, C172.1, C173.1, C174.2, C177.1, C178.1, C180.1, E12.2, E12.5, J133.2, J134.9, J143.1, R133.2, R137.2, R138.2, R141.2, U46.5, U47.VDD@36, U47.VDD@37, U48.7, U48.10
3.3V12: C184.1, C187.1, C188.1, C189.2, C192.1, C193.1, C195.1, E13.2, E13.5, J145.2, J146.9, J155.1, R145.2, R149.2, R150.2, R153.2, U50.5, U51.VDD@36, U51.VDD@37, U52.7, U52.10
3.3V13: C199.1, C202.1, C203.1, C204.2, C207.1, C208.1, C210.1, E14.2, E14.5, J157.2, J158.9, J167.1, R157.2, R161.2, R162.2, R165.2, U54.5, U55.VDD@36, U55.VDD@37, U56.7, U56.10
3.3V14: C214.1, C217.1, C218.1, C219.2, C222.1, C223.1, C225.1, E15.2, E15.5, J169.2, J170.9, J179.1, R169.2, R173.2, R174.2, R177.2, U58.5, U59.VDD@36, U59.VDD@37, U60.7, U60.10
3.3V15: C229.1, C232.1, C233.1, C234.2, C237.1, C238.1, C240.1, E16.2, E16.5, J181.2, J182.9, J191.1, R181.2, R185.2, R186.2, R189.2, U62.5, U63.VDD@36, U63.VDD@37, U64.7, U64.10
4: J26.2, U11.D40
5: J40.1, U15.D38
6: J38.2, U15.D40
7: J52.1, U19.D38
8: J7.1, U1.D38
9: J50.2, U19.D40
10: J2.2, U1.D40
11: J64.1, U23.D38
12: J62.2, U23.D40
13: J76.1, U27.D38
14: J74.2, U27.D40
15: J88.1, U31.D38
16: J86.2, U31.D40
17: J100.1, U35.D38
18: J98.2, U35.D40
19: J112.1, U39.D38
20: J110.2, U39.D40
21: J124.1, U43.D38
22: J122.2, U43.D40
23: J136.1, U47.D38
24: J134.2, U47.D40
25: J148.1, U51.D38
26: J146.2, U51.D40
27: J160.1, U55.D38
28: J158.2, U55.D40
29: J172.1, U59.D38
30: J170.2, U59.D40
31: J184.1, U63.D38
32: J182.2, U63.D40
!RESET: C20.2, C28.1, J2.10, J11.10, R14.1, S1.3, S1.4, U1.~RST
!RESET1: C24.2, C29.1, J8.10, J23.10, R21.1, S2.3, S2.4, U7.~RST
!RESET2: C40.2, C44.1, J26.10, J35.10, R33.1, S3.3, S3.4, U11.~RST
!RESET3: C55.2, C59.1, J38.10, J47.10, R45.1, S4.3, S4.4, U15.~RST
!RESET4: C70.2, C74.1, J50.10, J59.10, R57.1, S5.3, S5.4, U19.~RST
!RESET5: C85.2, C89.1, J62.10, J71.10, R69.1, S6.3, S6.4, U23.~RST
!RESET6: C100.2, C104.1, J74.10, J83.10, R81.1, S7.3, S7.4, U27.~RST
!RESET7: C115.2, C119.1, J86.10, J95.10, R93.1, S8.3, S8.4, U31.~RST
!RESET8: C130.2, C134.1, J98.10, J107.10, R105.1, S9.3, S9.4, U35.~RST
!RESET9: C145.2, C149.1, J110.10, J119.10, R117.1, S10.3, S10.4, U39.~RST
!RESET10: C160.2, C164.1, J122.10, J131.10, R129.1, S11.3, S11.4, U43.~RST
!RESET11: C175.2, C179.1, J134.10, J143.10, R141.1, S12.3, S12.4, U47.~RST
!RESET12: C190.2, C194.1, J146.10, J155.10, R153.1, S13.3, S13.4, U51.~RST
!RESET13: C205.2, C209.1, J158.10, J167.10, R165.1, S14.3, S14.4, U55.~RST
!RESET14: C220.2, C224.1, J170.10, J179.10, R177.1, S15.3, S15.4, U59.~RST
!RESET15: C235.2, C239.1, J182.10, J191.10, R189.1, S16.3, S16.4, U63.~RST
!RTS: C20.1, C21.1, R17.2, U6.4
!RTS1: C24.1, C25.1, R23.2, U8.4
!RTS2: C40.1, C41.1, R35.2, U12.4
!RTS3: C55.1, C56.1, R47.2, U16.4
!RTS4: C70.1, C71.1, R59.2, U20.4
!RTS5: C85.1, C86.1, R71.2, U24.4
!RTS6: C100.1, C101.1, R83.2, U28.4
!RTS7: C115.1, C116.1, R95.2, U32.4
!RTS8: C130.1, C131.1, R107.2, U36.4
!RTS9: C145.1, C146.1, R119.2, U40.4
!RTS10: C160.1, C161.1, R131.2, U44.4
!RTS11: C175.1, C176.1, R143.2, U48.4
!RTS12: C190.1, C191.1, R155.2, U52.4
!RTS13: C205.1, C206.1, R167.2, U56.4
!RTS14: C220.1, C221.1, R179.2, U60.4
!RTS15: C235.1, C236.1, R191.2, U64.4
BOOT: C21.2, R15.2, U1.BOOT
BOOT1: C25.2, R22.2, U7.BOOT
BOOT2: C41.2, R34.2, U11.BOOT
BOOT3: C56.2, R46.2, U15.BOOT
BOOT4: C71.2, R58.2, U19.BOOT
BOOT5: C86.2, R70.2, U23.BOOT
BOOT6: C101.2, R82.2, U27.BOOT
BOOT7: C116.2, R94.2, U31.BOOT
BOOT8: C131.2, R106.2, U35.BOOT
BOOT9: C146.2, R118.2, U39.BOOT
BOOT10: C161.2, R130.2, U43.BOOT
BOOT11: C176.2, R142.2, U47.BOOT
BOOT12: C191.2, R154.2, U51.BOOT
BOOT13: C206.2, R166.2, U55.BOOT
BOOT14: C221.2, R178.2, U59.BOOT
BOOT15: C236.2, R190.2, U63.BOOT
CC1: J10.A5, R13.2
CC2: J10.B5, R11.2
CC3: J22.B5, R19.2
CC4: J22.A5, R20.2
CC5: J34.B5, R31.2
CC6: J34.A5, R32.2
CC7: J46.B5, R43.2
CC8: J46.A5, R44.2
CC9: J58.B5, R55.2
CC10: J58.A5, R56.2
CC11: J70.B5, R67.2
CC12: J70.A5, R68.2
CC13: J82.B5, R79.2
CC14: J82.A5, R80.2
CC15: J94.B5, R91.2
CC16: J94.A5, R92.2
CC17: J106.B5, R103.2
CC18: J106.A5, R104.2
CC19: J118.B5, R115.2
CC20: J118.A5, R116.2
CC21: J130.B5, R127.2
CC22: J130.A5, R128.2
CC23: J142.B5, R139.2
CC24: J142.A5, R140.2
CC25: J154.B5, R151.2
CC26: J154.A5, R152.2
CC27: J166.B5, R163.2
CC28: J166.A5, R164.2
CC29: J178.B5, R175.2
CC30: J178.A5, R176.2
CC31: J190.B5, R187.2
CC32: J190.A5, R188.2
D+1: J10.A6, J10.B6, U6.1
D+2: J22.A6, J22.B6, U8.1
D+3: J34.A6, J34.B6, U12.1
D+4: J46.A6, J46.B6, U16.1
D+5: J58.A6, J58.B6, U20.1
D+6: J70.A6, J70.B6, U24.1
D+7: J82.A6, J82.B6, U28.1
D+8: J94.A6, J94.B6, U32.1
D+9: J106.A6, J106.B6, U36.1
D+10: J118.A6, J118.B6, U40.1
D+11: J130.A6, J130.B6, U44.1
D+12: J142.A6, J142.B6, U48.1
D+13: J154.A6, J154.B6, U52.1
D+14: J166.A6, J166.B6, U56.1
D+15: J178.A6, J178.B6, U60.1
D+16: J190.A6, J190.B6, U64.1
D-1: J10.A7, J10.B7, U6.2
D-2: J22.A7, J22.B7, U8.2
D-3: J34.A7, J34.B7, U12.2
D-4: J46.A7, J46.B7, U16.2
D-5: J58.A7, J58.B7, U20.2
D-6: J70.A7, J70.B7, U24.2
D-7: J82.A7, J82.B7, U28.2
D-8: J94.A7, J94.B7, U32.2
D-9: J106.A7, J106.B7, U36.2
D-10: J118.A7, J118.B7, U40.2
D-11: J130.A7, J130.B7, U44.2
D-12: J142.A7, J142.B7, U48.2
D-13: J154.A7, J154.B7, U52.2
D-14: J166.A7, J166.B7, U56.2
D-15: J178.A7, J178.B7, U60.2
D-16: J190.A7, J190.B7, U64.2
GND: C1.2, C5.2, C6.2, C8.2, C9.2, C12.1, C13.1, C17.2, C18.2, C19.1, C22.2, C23.2, C28.2, D1.C, D6.C, E1.3, E1.6, E1.7, E1.8, J1.1, J2.11, J3.1, J4.2, J9.1, J9.2, J9.3, J9.4, J9.5, J9.6, J9.7, J10.GND, J10.GND2, J11.3, J11.5, J11.9, J12.1, J13.1, J13.2, J13.3, J13.4, J13.5, J13.6, J13.7, J13.8, J13.9, J13.10, J13.11, J13.12, J14.1, J14.2, R5.1, R11.1, R13.1, R15.1, R17.1, S1.1, S1.2, U1.GND@1, U1.GND@22, U1.GND@38, U1.GND@39, U1.GND@47, U1.GND@59, U2.2, U3.2, U6.3
GND1: C2.2, C3.2, C4.2, C7.2, C10.1, C11.1, C14.2, C15.2, C16.1, C26.2, C27.2, C29.2, C30.2, D8.C, D9.C, E2.3, E2.6, E2.7, E2.8, J6.1, J8.11, J17.1, J18.1, J18.2, J18.3, J18.4, J18.5, J18.6, J18.7, J19.1, J20.1, J20.2, J20.3, J20.4, J20.5, J20.6, J20.7, J20.8, J20.9, J20.10, J20.11, J20.12, J21.1, J21.2, J22.GND, J22.GND2, J23.3, J23.5, J23.9, J24.2, R7.1, R19.1, R20.1, R22.1, R23.1, S2.1, S2.2, U4.2, U5.2, U7.GND@1, U7.GND@22, U7.GND@38, U7.GND@39, U7.GND@47, U7.GND@59, U8.3
GND2: C31.2, C32.2, C33.2, C34.2, C35.1, C36.1, C37.2, C38.2, C39.1, C42.2, C43.2, C44.2, C45.2, D15.C, D16.C, E3.3, E3.6, E3.7, E3.8, J25.1, J26.11, J29.1, J30.1, J30.2, J30.3, J30.4, J30.5, J30.6, J30.7, J31.1, J32.1, J32.2, J32.3, J32.4, J32.5, J32.6, J32.7, J32.8, J32.9, J32.10, J32.11, J32.12, J33.1, J33.2, J34.GND, J34.GND2, J35.3, J35.5, J35.9, J36.2, R27.1, R31.1, R32.1, R34.1, R35.1, S3.1, S3.2, U9.2, U10.2, U11.GND@1, U11.GND@22, U11.GND@38, U11.GND@39, U11.GND@47, U11.GND@59, U12.3
GND3: C46.2, C47.2, C48.2, C49.2, C50.1, C51.1, C52.2, C53.2, C54.1, C57.2, C58.2, C59.2, C60.2, D22.C, D23.C, E4.3, E4.6, E4.7, E4.8, J37.1, J38.11, J41.1, J42.1, J42.2, J42.3, J42.4, J42.5, J42.6, J42.7, J43.1, J44.1, J44.2, J44.3, J44.4, J44.5, J44.6, J44.7, J44.8, J44.9, J44.10, J44.11, J44.12, J45.1, J45.2, J46.GND, J46.GND2, J47.3, J47.5, J47.9, J48.2, R39.1, R43.1, R44.1, R46.1, R47.1, S4.1, S4.2, U13.2, U14.2, U15.GND@1, U15.GND@22, U15.GND@38, U15.GND@39, U15.GND@47, U15.GND@59, U16.3
GND4: C61.2, C62.2, C63.2, C64.2, C65.1, C66.1, C67.2, C68.2, C69.1, C72.2, C73.2, C74.2, C75.2, D29.C, D30.C, E5.3, E5.6, E5.7, E5.8, J49.1, J50.11, J53.1, J54.1, J54.2, J54.3, J54.4, J54.5, J54.6, J54.7, J55.1, J56.1, J56.2, J56.3, J56.4, J56.5, J56.6, J56.7, J56.8, J56.9, J56.10, J56.11, J56.12, J57.1, J57.2, J58.GND, J58.GND2, J59.3, J59.5, J59.9, J60.2, R51.1, R55.1, R56.1, R58.1, R59.1, S5.1, S5.2, U17.2, U18.2, U19.GND@1, U19.GND@22, U19.GND@38, U19.GND@39, U19.GND@47, U19.GND@59, U20.3
GND5: C76.2, C77.2, C78.2, C79.2, C80.1, C81.1, C82.2, C83.2, C84.1, C87.2, C88.2, C89.2, C90.2, D36.C, D37.C, E6.3, E6.6, E6.7, E6.8, J61.1, J62.11, J65.1, J66.1, J66.2, J66.3, J66.4, J66.5, J66.6, J66.7, J67.1, J68.1, J68.2, J68.3, J68.4, J68.5, J68.6, J68.7, J68.8, J68.9, J68.10, J68.11, J68.12, J69.1, J69.2, J70.GND, J70.GND2, J71.3, J71.5, J71.9, J72.2, R63.1, R67.1, R68.1, R70.1, R71.1, S6.1, S6.2, U21.2, U22.2, U23.GND@1, U23.GND@22, U23.GND@38, U23.GND@39, U23.GND@47, U23.GND@59, U24.3
GND6: C91.2, C92.2, C93.2, C94.2, C95.1, C96.1, C97.2, C98.2, C99.1, C102.2, C103.2, C104.2, C105.2, D43.C, D44.C, E7.3, E7.6, E7.7, E7.8, J73.1, J74.11, J77.1, J78.1, J78.2, J78.3, J78.4, J78.5, J78.6, J78.7, J79.1, J80.1, J80.2, J80.3, J80.4, J80.5, J80.6, J80.7, J80.8, J80.9, J80.10, J80.11, J80.12, J81.1, J81.2, J82.GND, J82.GND2, J83.3, J83.5, J83.9, J84.2, R75.1, R79.1, R80.1, R82.1, R83.1, S7.1, S7.2, U25.2, U26.2, U27.GND@1, U27.GND@22, U27.GND@38, U27.GND@39, U27.GND@47, U27.GND@59, U28.3
GND7: C106.2, C107.2, C108.2, C109.2, C110.1, C111.1, C112.2, C113.2, C114.1, C117.2, C118.2, C119.2, C120.2, D50.C, D51.C, E8.3, E8.6, E8.7, E8.8, J85.1, J86.11, J89.1, J90.1, J90.2, J90.3, J90.4, J90.5, J90.6, J90.7, J91.1, J92.1, J92.2, J92.3, J92.4, J92.5, J92.6, J92.7, J92.8, J92.9, J92.10, J92.11, J92.12, J93.1, J93.2, J94.GND, J94.GND2, J95.3, J95.5, J95.9, J96.2, R87.1, R91.1, R92.1, R94.1, R95.1, S8.1, S8.2, U29.2, U30.2, U31.GND@1, U31.GND@22, U31.GND@38, U31.GND@39, U31.GND@47, U31.GND@59, U32.3
GND8: C121.2, C122.2, C123.2, C124.2, C125.1, C126.1, C127.2, C128.2, C129.1, C132.2, C133.2, C134.2, C135.2, D57.C, D58.C, E9.3, E9.6, E9.7, E9.8, J97.1, J98.11, J101.1, J102.1, J102.2, J102.3, J102.4, J102.5, J102.6, J102.7, J103.1, J104.1, J104.2, J104.3, J104.4, J104.5, J104.6, J104.7, J104.8, J104.9, J104.10, J104.11, J104.12, J105.1, J105.2, J106.GND, J106.GND2, J107.3, J107.5, J107.9, J108.2, R99.1, R103.1, R104.1, R106.1, R107.1, S9.1, S9.2, U33.2, U34.2, U35.GND@1, U35.GND@22, U35.GND@38, U35.GND@39, U35.GND@47, U35.GND@59, U36.3
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

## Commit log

2019-07-01 Add TPs for I2C lines going to Qwiic connector.
    [Artemis-Nano.brd]
2019-07-01 Rename to RedBoard
    [RedBoard-Artemis-Nano.brd, RedBoard-Artemis-Nano.sch]
2019-07-03 Changed silk around PSWC PTH.
    [RedBoard-Artemis-Nano.brd, RedBoard-Artemis-Nano.sch]
2019-07-03 Adding production panels
    [RedBoard-Artemis-Nano-Panel.GBL, RedBoard-Artemis-Nano-Panel.GBO, RedBoard-Artemis-Nano-Panel.GBP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]
2019-07-03 Add OSHW logo
    [RedBoard-Artemis-Nano.brd, RedBoard-Artemis-Nano.sch]
2026-03-12 updated model with button and qwiic connector

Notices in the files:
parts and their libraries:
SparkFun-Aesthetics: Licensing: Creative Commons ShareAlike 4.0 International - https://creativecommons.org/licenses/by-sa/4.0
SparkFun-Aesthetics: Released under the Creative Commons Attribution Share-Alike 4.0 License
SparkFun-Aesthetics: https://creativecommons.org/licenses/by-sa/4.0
